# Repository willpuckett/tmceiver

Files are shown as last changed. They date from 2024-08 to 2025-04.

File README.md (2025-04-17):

# TMCeiver

A drop in CAN transceiver for Robin Nano V3. 

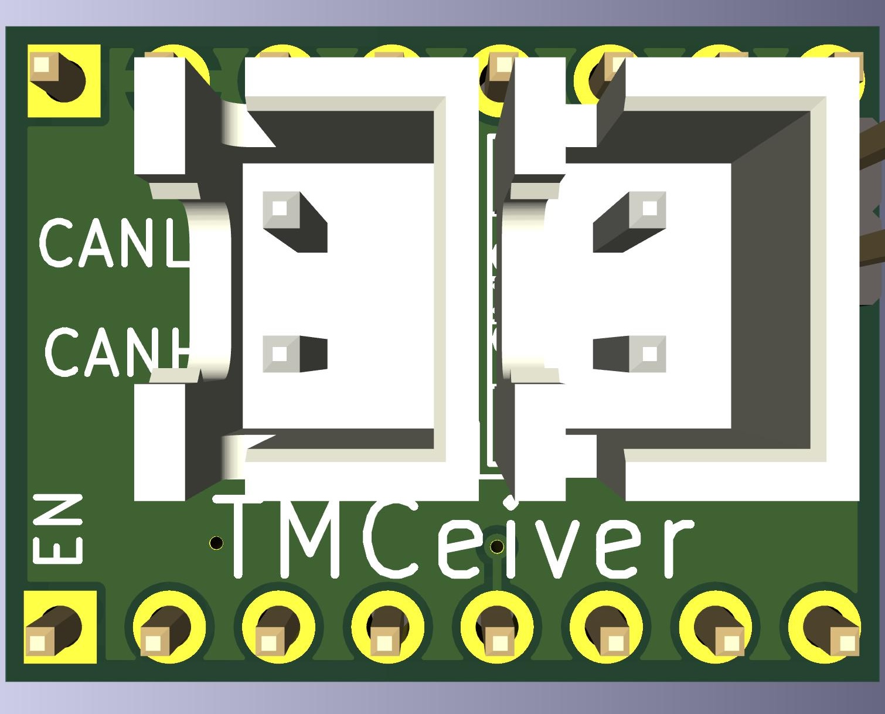
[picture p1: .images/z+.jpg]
TMCeiver


TMCeiver utilizes a spare stepper slot on Robin Nano V3 to provide CAN connectivity. 

## Features

- CANFD capable (not yet supported in Klipper)
- Excellent reliability—no CAN retransmits in several months of testing
- Jumperable 120 Ω termination resistor
- Less cabling to crimp

## Installation

Start with power off.

1. Remove the stepper driver from the slot you want to use.
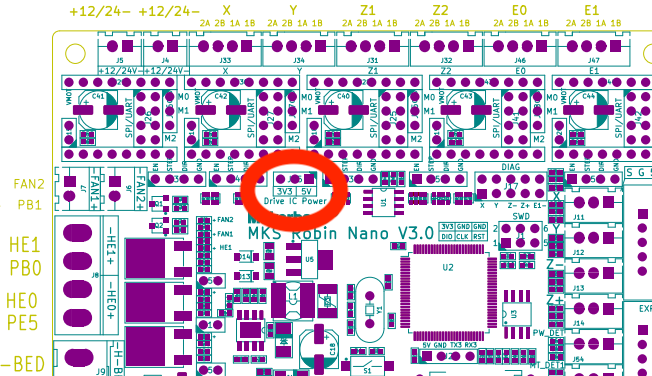
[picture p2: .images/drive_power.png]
jumper to 5v
2. Make sure the steppers are jumpered to run at 5v. <br />
3. Use jumpers to jump the MISO and SCK pins to the TMCeiver. MISO and SCK are the first and third pins from the mcu side of the stepper slot.  If you're not sure, you can jumper the entire row (all four pins). <br />MISO & SDK or all pins
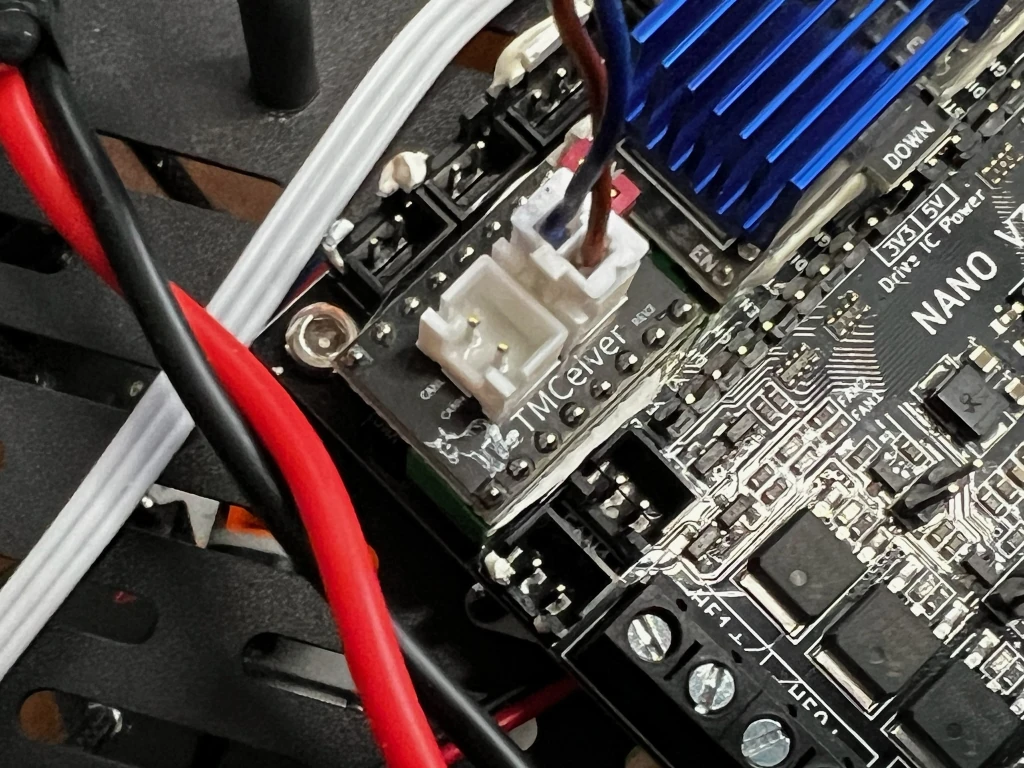
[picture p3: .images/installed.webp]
Installed tmceiver
4. Insert TMCeiver into the slot, aligning the EN silkscreen with the EN slot on the board (for rev3, align the octule icon with EN). If you get it backwards, nothing will be damaged, but it won't work. <br />
5. Connect the CAN bus to the JST XH connector. 
6. Terminate the CAN bus by placing a jumper on the pins labeled `TERM`.
7. You can connect a second CAN device to the other JST XH connector, in which case you should remove the jumper from the `TERM` pins and terminate the bus at the last device.
8. Compile and flash your board (Use pins 'PD0/PD1' for the CAN bus) with the [Katapult](https://github.com/arksine/katapult) bootloader. You can build the Katapult Deployer and flash it via SD Card, or follow [these instructions](https://github.com/willpuckett/config/blob/main/reference/MKS/Robin_Nano_V3.1.md#flashing-katapult) to flash with OpenOCD.
9. Flash [Klipper](https://github.com/klipper3d/klipper). If you're connecting to the CAN bus with USB via the Robin Nano V3, you'll need to compile in CAN bus bridge mode. 

## Schematic

Schematic

## Acquisition

Use the files in [production_files](jlcpcb/production_files/) directory to order the PCB from your favorite board house. If you're trying to lower costs, you can opt for assembly on the bottom side only, and hand solder the top side components.

There's also a couple available from my first run [here](https://octule.com).

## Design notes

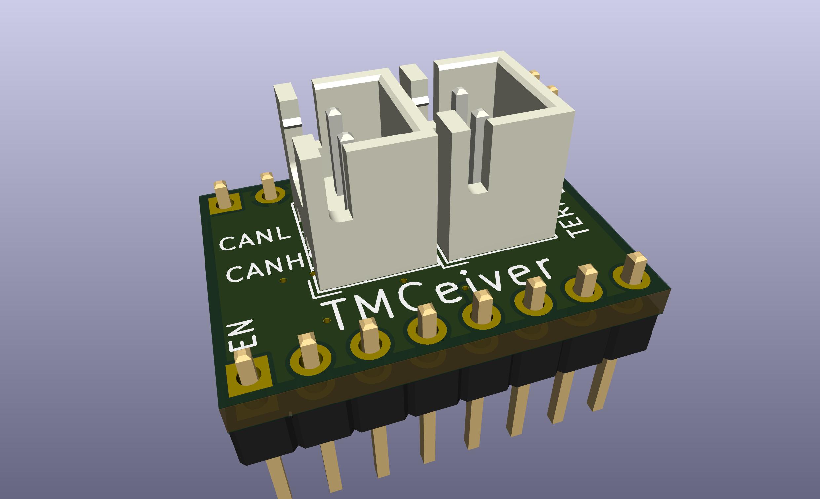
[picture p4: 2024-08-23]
.images/side.jpg

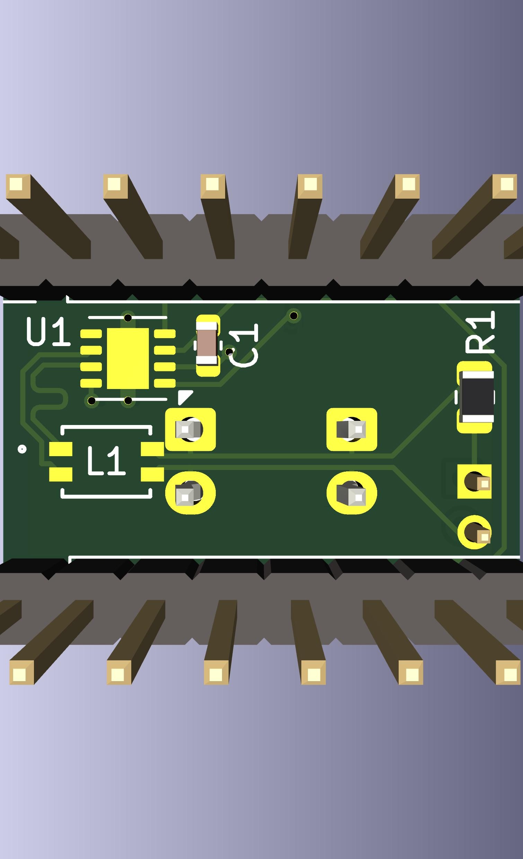
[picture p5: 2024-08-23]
.images/z-.jpg

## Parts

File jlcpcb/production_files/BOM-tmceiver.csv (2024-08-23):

Comment | Designator | Footprint | LCSC
RC0805FR-07120RL | R1 | R_0805_2012Metric | C114245
B-2100S08P-A110 | J1,J2 | PinHeader_1x08_P2.54mm_Vertical | C124381
B2B-XH-A (LF)(SN) | CN1,CN2 | JST_XH_B2B-XH-A_1x02_P2.50mm_Vertical | C158012
CL10B104KB8NNNC | C1 | C_0603_1608Metric | C1591
TCAN1044ADRBRQ1 | U1 | VSON-8-1EP_3x3mm_P0.65mm_EP1.65x2.4mm | C3234118
ZX-PZ2.0-1-2PZZ | J3 | PinHeader_1x02_P2.00mm_Vertical | C7501287
ACT1210-510-2P-TL00 | L1 | CHOKE_10-2P-TL00_TDK | C95572

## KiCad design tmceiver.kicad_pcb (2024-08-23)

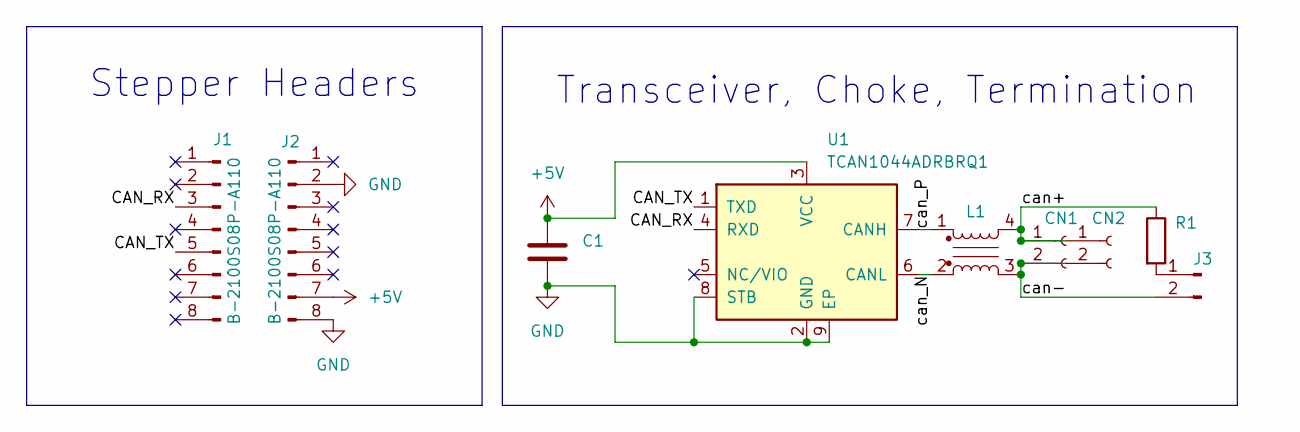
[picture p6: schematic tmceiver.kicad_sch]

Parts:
C1: CL10B104KB8NNNC; C_0603_1608Metric
CN1, CN2: B2B-XH-A (LF)(SN); JST_XH_B2B-XH-A_1x02_P2.50mm_Vertical
J1, J2: B-2100S08P-A110; PinHeader_1x08_P2.54mm_Vertical
J3: ZX-PZ2.0-1-2PZZ; PinHeader_1x02_P2.00mm_Vertical
L1: ACT1210-510-2P-TL00; CHOKE_10-2P-TL00_TDK
R1: RC0805FR-07120RL; R_0805_2012Metric
U1: TCAN1044ADRBRQ1; VSON-8-1EP_3x3mm_P0.65mm_EP1.65x2.4mm

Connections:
+5V: C1.1, J2.7, U1.3 (VCC)
/CAN_RX: J1.3, U1.4 (RXD)
/CAN_TX: J1.5, U1.1 (TXD)
/can+: CN1.1, CN2.1, L1.4, R1.1
/can-: CN1.2, CN2.2, J3.2, L1.3
/can_N: L1.2, U1.6 (CANL)
/can_P: L1.1, U1.7 (CANH)
GND: C1.2, J2.2, J2.8, U1.2 (GND), U1.8 (STB), U1.9 (EP)
unnamed: J3.1, R1.2

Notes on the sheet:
Transceiver, Choke, Termination
Stepper Headers

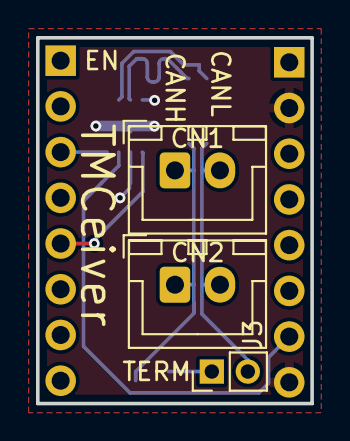
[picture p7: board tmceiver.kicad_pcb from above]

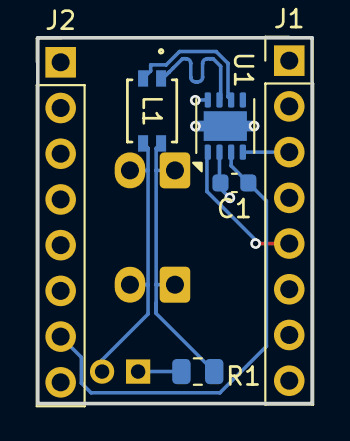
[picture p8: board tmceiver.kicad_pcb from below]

Board: 2 copper layers, 15.2 x 20.3 mm, 9 parts (6 on the bottom side), 9 nets.
